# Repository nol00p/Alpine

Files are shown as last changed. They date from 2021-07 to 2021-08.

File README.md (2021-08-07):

# The Alpine Project

this the final result:

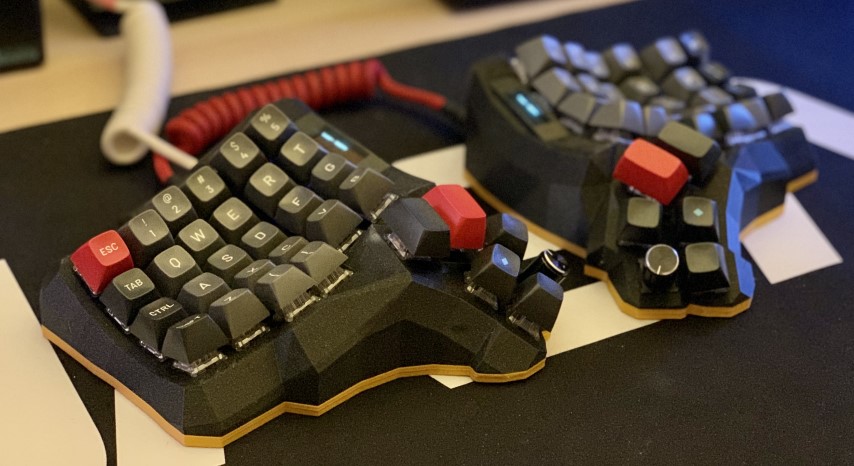
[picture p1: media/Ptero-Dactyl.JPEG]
Ptero-Dactyl


# Acknoledgement
**Special thanks to [u/j_oshreve](https://www.reddit.com/user/j_oshreve/) on Reddit** for all his work on https://github.com/joshreve/dactyl-keyboard. Without all his is doing this project would not have been possible. 

I would note this repo would gave me a great guide to get to a working product. https://github.com/OutstandingOof/ducktyl-manuform

if you have questions on the build or any of the tools I used hit me up reddit [u/loss_of_signal](https://www.reddit.com/user/loss_of_signal)

# Though Process
the aim of the build is to try to get as clean a result as possible with all the features fully integrated in the case design. both the LCD are fully integrated in the case. the trays on both sides are mirrored to avoid crossing the trrs and the usb. 

# requirements 
* 3 Printer for : 
  * case: both sides top and bottom
  * tray holder: both sides 
  * ec11 adapters
  * LCD tray
* Screws: whatert M3 screws
* Screw inserts
* diodes: 1N4148
* wires: I recommend single core wire, it is much easier to work with
* controllers: Elite C or Pro Micro x2
* oled screens: SSD1306 128x32 0,91" OLED Display x2
* ec11 rotary encoders x2 
* Kailh hot swap sockets
* switches
* keycaps

# The Build
## The case
all the 3D design and case generation was done thanks to the awesome work from u/j_oshrev at https://github.com/joshreve/dactyl-keyboard
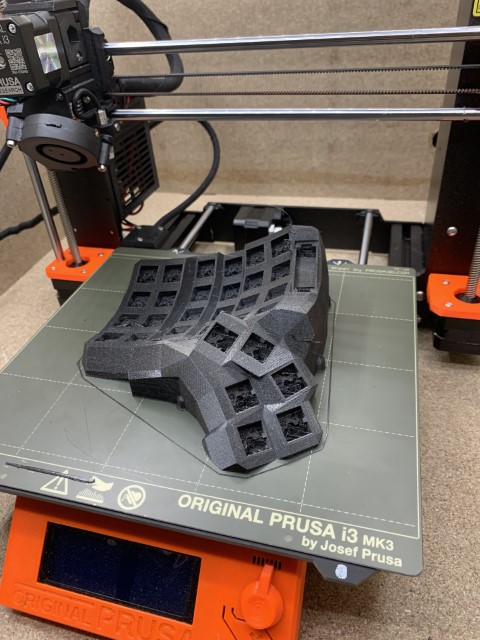
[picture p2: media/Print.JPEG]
print


After the printing goes the painfully long process of picking out all of the support material, beeing carefull not to break anything. 

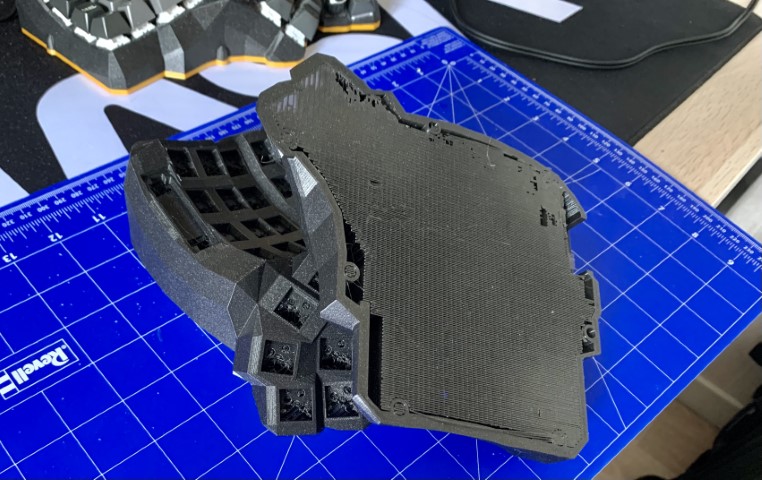
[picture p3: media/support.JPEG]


once the case is cleaned up, get the rest od teh component printed and install the sockets. 

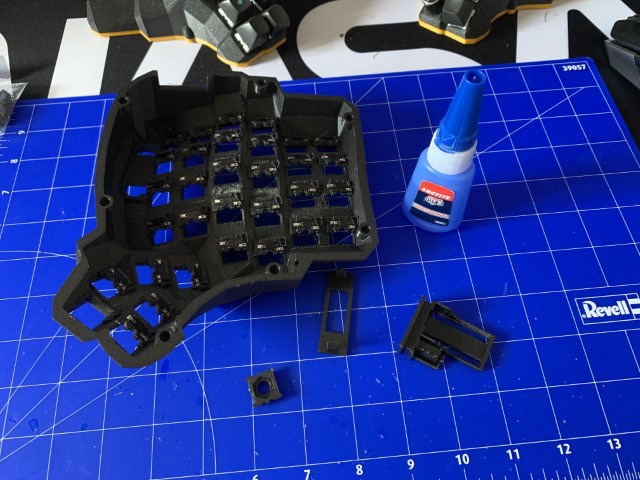
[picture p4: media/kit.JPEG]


for this build I forked the loligagger tray to have a mirror version so that the usb and trrs wouldn't get crossed 

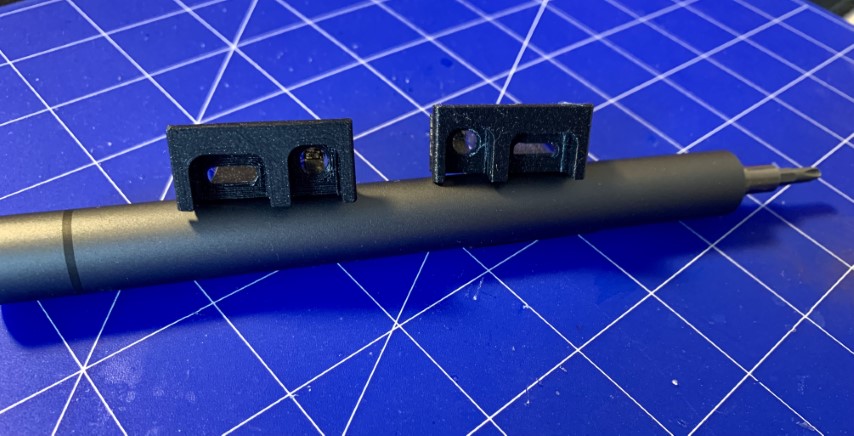
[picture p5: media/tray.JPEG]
tray

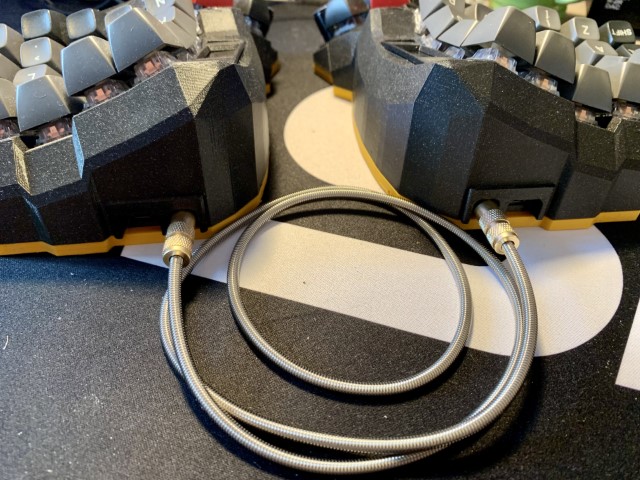
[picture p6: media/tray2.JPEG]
tray2


## Wiring 

the wiring is pretty straigh forward, juste take your time and use the right type of wires. I recommand signle core wire. for the wiring i follow this: 
right

left

this key here is to get the diode orientation right! the black line on the diodes should all be connected together to from the row. the idea is that the current would not go back in the switch when activated. 

### The oled screens
connect GND to GND, VCC to VCC, SDA to pin 2 and SCL to pin 3.

### Rotary Encoders
To add the rotary encoder, wire the two pins on one side into the matrix, just like any other switch (press the encoder acts like any other switch). f
From the other side of the encoder (the one with 3 pins) connect the middle one to GND. The two outer pins of the other side have to be wired to the pins A2 and A3. more details bellow.
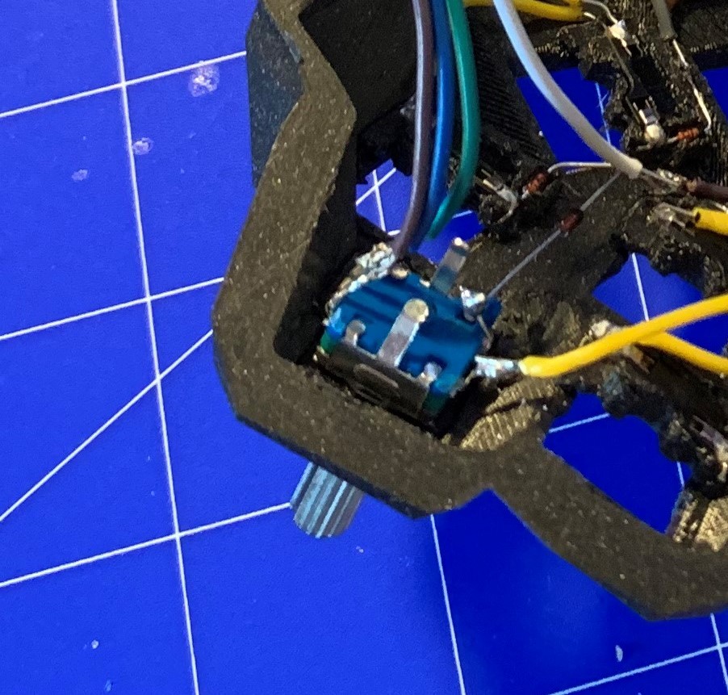
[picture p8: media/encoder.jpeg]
encoder


### the controller

the final part is to connect all those wire to the controller. 

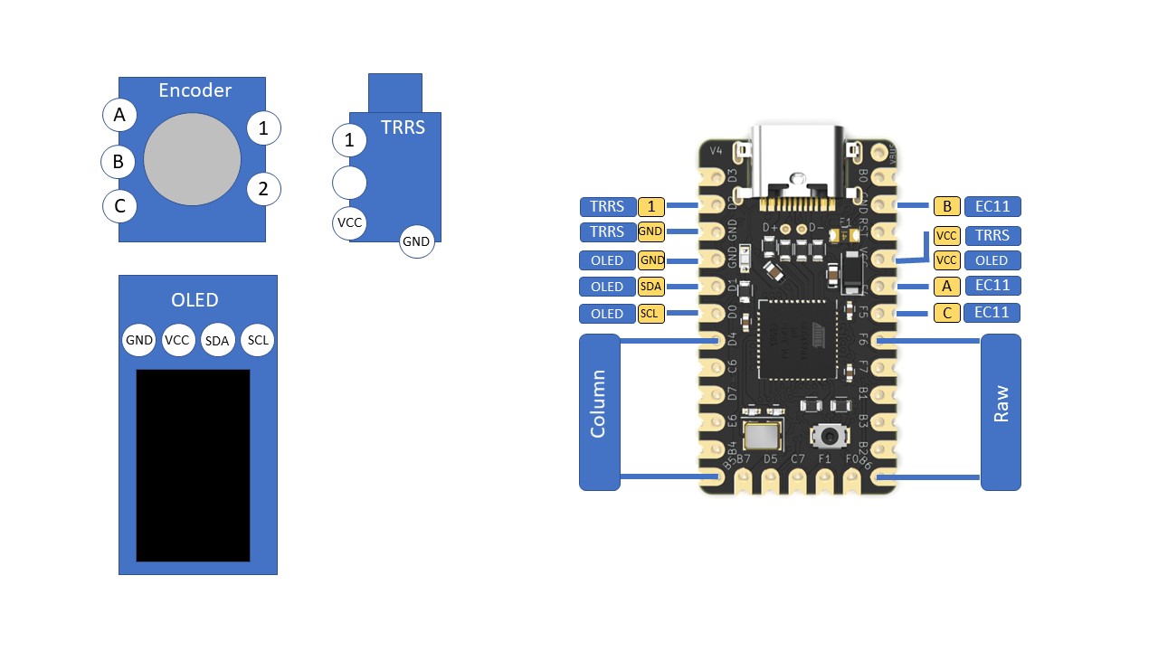
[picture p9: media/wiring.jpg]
wiring


the wiring for a Pro Micro controler is the exact same.

the end result is something like this

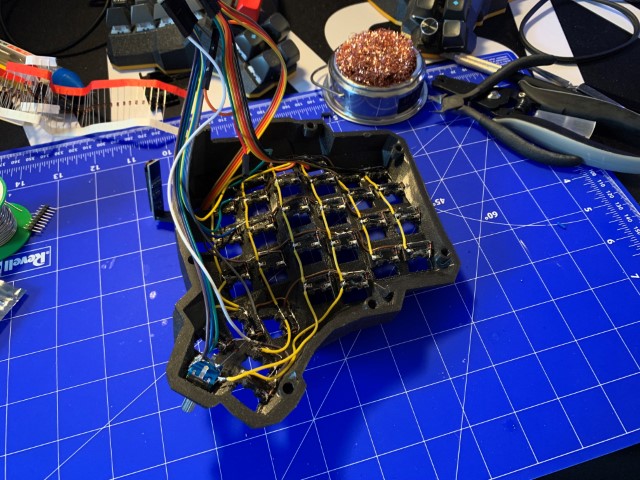
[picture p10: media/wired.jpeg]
wired


# The Code
For simplicity sake, I have opted to install the elite-c on both sides. This makes flashing much easier by not having to deal with different loaders on each sides.

note: all the oled management code is pulled from the lily58. I need to spend time (and get help) to figure out how to better use the screen and get a setup that I actully like.

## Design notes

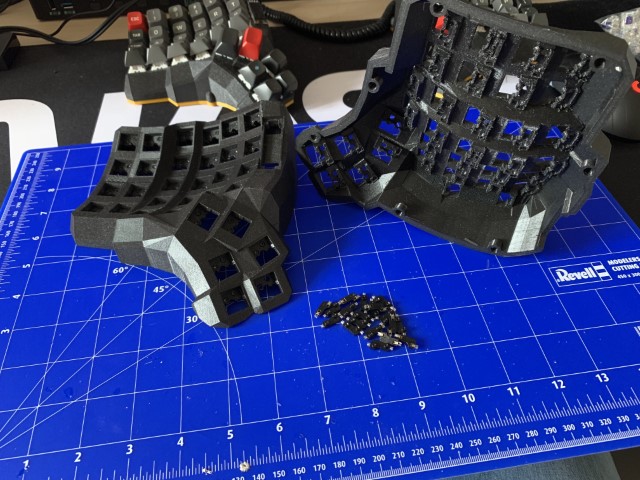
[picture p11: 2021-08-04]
media/Ptero-Dactyl 4 (Small).JPEG

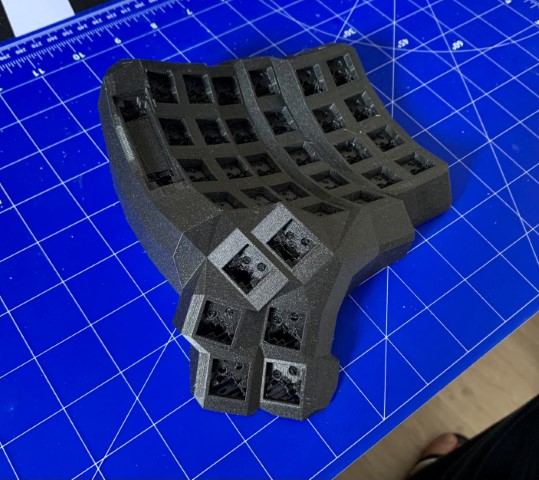
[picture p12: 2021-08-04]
media/right.JPEG

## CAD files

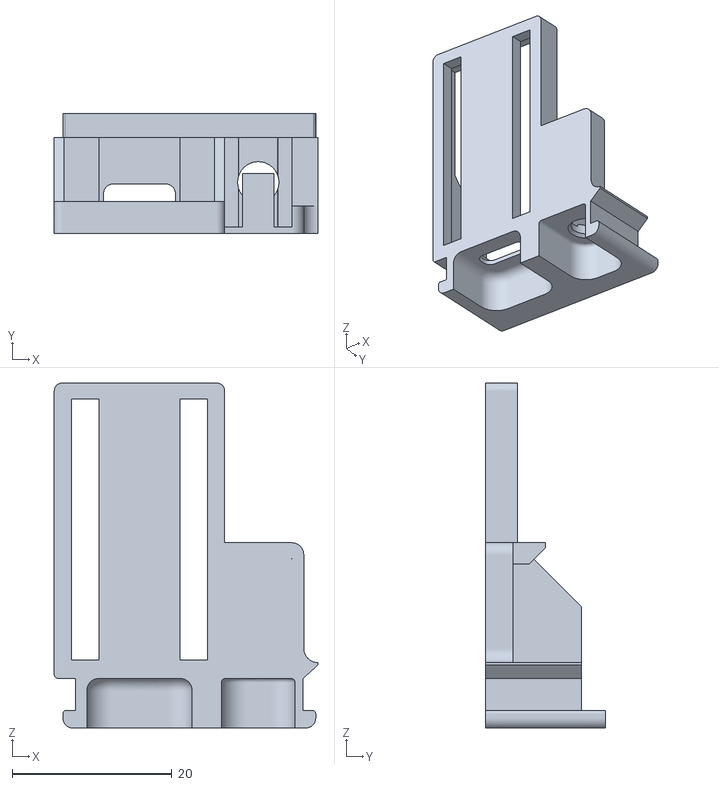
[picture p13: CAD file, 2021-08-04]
stl/Ptero-Dactyl_Left-tray-elite-c.stl
33.0 x 15.0 x 43.2

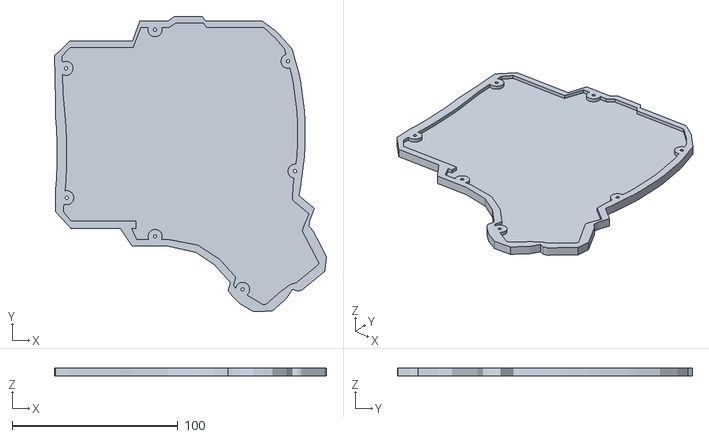
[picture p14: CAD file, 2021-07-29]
stl/bottom_left.stl
164.3 x 178.2 x 5.00

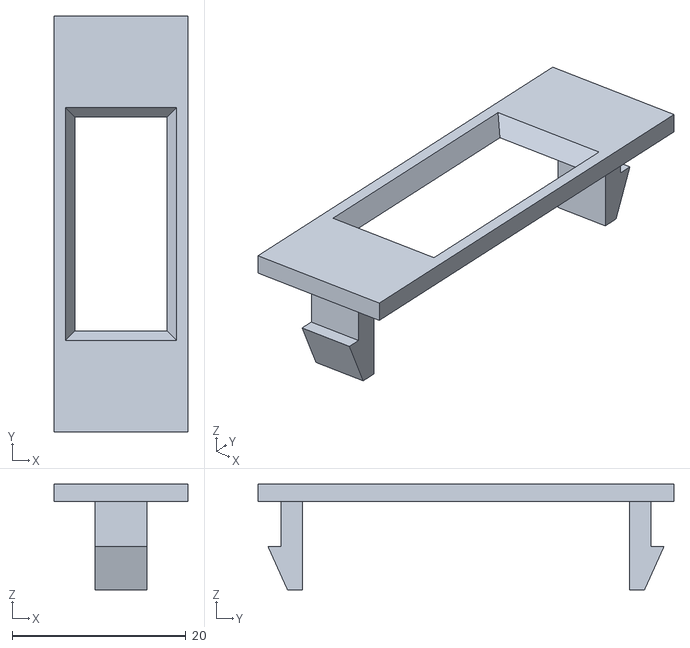
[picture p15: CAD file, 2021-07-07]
stl/oled.stl
15.4 x 47.9 x 12.2

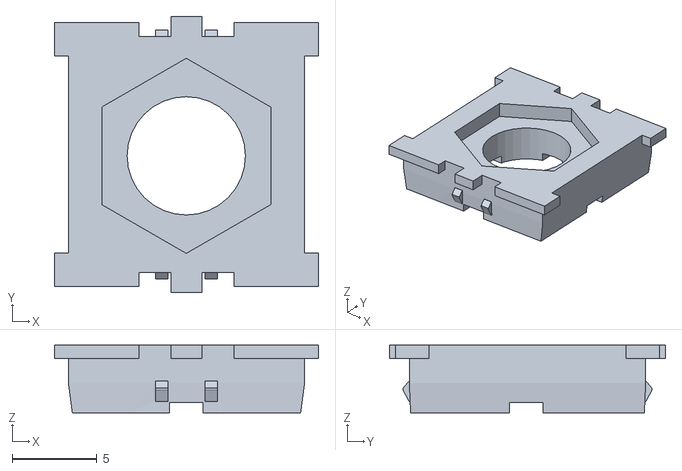
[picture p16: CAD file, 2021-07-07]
stl/EC11_to_MX_Adapter_V2.stl
15.6 x 16.3 x 4.00

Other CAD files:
stl/bottom_right.stl
stl/loligagger-external-holder-elite-c-v1.stl

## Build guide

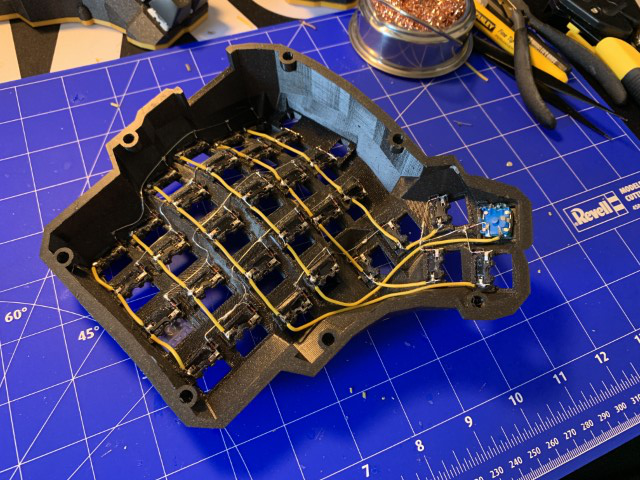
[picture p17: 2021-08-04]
media/wiring2.JPEG

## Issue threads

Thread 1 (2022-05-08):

Lessons Learned

bosd, 2022-05-08:
Thanks for posting this awesome project.
I am currently designing my first build.
Would like to base it on this design.

Do you have some lessons learned?
Are there some items you would change the second time??

Want to fork this to incorporate the following mods:
- Use the Mxledbit for rgb underglow for the keys. (also hotswappable)
- use acrylic bottom plate for underglow effect.
- Add trackpoint stick

nol00p, 2022-05-09:
not much really the build was pretty straight forward. If I had to do it again I would do the same.
I am interested to see how you go about integrating the trackpoint  - I toyed with the idea, but I don't like the massive ball, and would rather have it where the right potentiometer is.

I used similar small PCB in an other build, and at the end of the day I found it easier to just full hand wire.

I would assume as well that the stl files wouldn't be sutable for PCB mount.

bosd, 2022-05-09:
Glad to hear that!
I've had a lot of problems by getting the generator of [joshreve ](https://github.com/joshreve/dactyl-keyboard)or the [wylderbyld ](https://github.com/bullwinkle3000/dactyl-keyboard) up and running.
(mainly deu to Cadquery issues)
Did'nt want any more delays, so I dropped the idea of integrating a trackball.
Used your STL files and placed an order for the prints at treatstock.com.

Instead of the trackball, I'm going to attempt to include a trackpoint:
https://github.com/alonswartz/trackpoint/blob/master/README.md

nol00p, 2022-05-13:
that is an interesting idea. I would love to see https://shop.pimoroni.com/products/trackball-breakout?variant=27672765038675
being integrated (just below the screen for example)
anyhow, good luck for the build and share the results :)

nol00p, 2022-05-30:
hello, that's odd - looks like the printing company changed the dimensions slightly. I didn't have those issues and others either as far as I know.

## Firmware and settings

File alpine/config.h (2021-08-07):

/*
Copyright 2012 Jun Wako <wakojun@gmail.com>
Copyright 2015 Jack Humbert

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
You should have received a copy of the GNU General Public License
along with this program.  If not, see <http://www.gnu.org/licenses/>.
*/

#pragma once

#include "config_common.h"

/* USB Device descriptor parameter */
#define VENDOR_ID       0xFEED
#define PRODUCT_ID      0x3060
#define DEVICE_VER      0x0001
#define MANUFACTURER    nol00p

// defined in subfolder
#define DESCRIPTION     The Alpine Project ergo keyboard
#define PRODUCT         alpine 5x6

/* mouse config */
#define MOUSEKEY_INTERVAL       20
#define MOUSEKEY_DELAY          0
#define MOUSEKEY_TIME_TO_MAX    60
#define MOUSEKEY_MAX_SPEED      7
#define MOUSEKEY_WHEEL_DELAY 0

/* Set 0 if debouncing isn't needed */
#define DEBOUNCE 5

/* serial.c configuration for split keyboard */
#define SOFT_SERIAL_PIN D2

/* Mechanical locking support. Use KC_LCAP, KC_LNUM or KC_LSCR instead in keymap */
#define LOCKING_SUPPORT_ENABLE
/* Locking resynchronize hack */
#define LOCKING_RESYNC_ENABLE

/* Enables This makes it easier for fast typists to use dual-function keys */
#define PERMISSIVE_HOLD


/* key matrix size */
// Rows are doubled-up
#define MATRIX_ROWS 12
#define MATRIX_COLS 6

// wiring of each half
#define MATRIX_COL_PINS { D4, C6, D7, E6, B4, B5 }
#define MATRIX_ROW_PINS { F6, F7, B1, B3, B2, B6 }

#define DIODE_DIRECTION COL2ROW

// WS2812 RGB LED strip input and number of LEDs
#define RGB_DI_PIN D3
#define RGBLED_NUM 12

/* define if matrix has ghost */
//#define MATRIX_HAS_GHOST

/* number of backlight levels */
// #define BACKLIGHT_LEVELS 3

// wiring of the encoder (right side)
#define ENCODERS_PAD_A { F4 }
#define ENCODERS_PAD_B { F5 }

// define de timing for the tap dance time out
#define TAPPING_TERM 200


/*
 * Feature disable options
 *  These options are also useful to firmware size reduction.
 */

/* disable debug print */
// #define NO_DEBUG

/* disable print */
// #define NO_PRINT

/* disable action features */
//#define NO_ACTION_LAYER
//#define NO_ACTION_TAPPING
//#define NO_ACTION_ONESHOT
//#define NO_ACTION_MACRO
//#define NO_ACTION_FUNCTION

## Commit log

2021-07-29 bottom plates
    [bottom_left.stl, bottom_right.stl]
2021-07-29 old plate
    [Plate.stl]

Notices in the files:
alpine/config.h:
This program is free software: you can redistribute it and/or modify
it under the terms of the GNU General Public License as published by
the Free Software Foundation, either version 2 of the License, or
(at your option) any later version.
